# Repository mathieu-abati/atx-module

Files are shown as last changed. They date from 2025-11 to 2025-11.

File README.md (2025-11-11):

# RaspberryPi ATX PSU control module

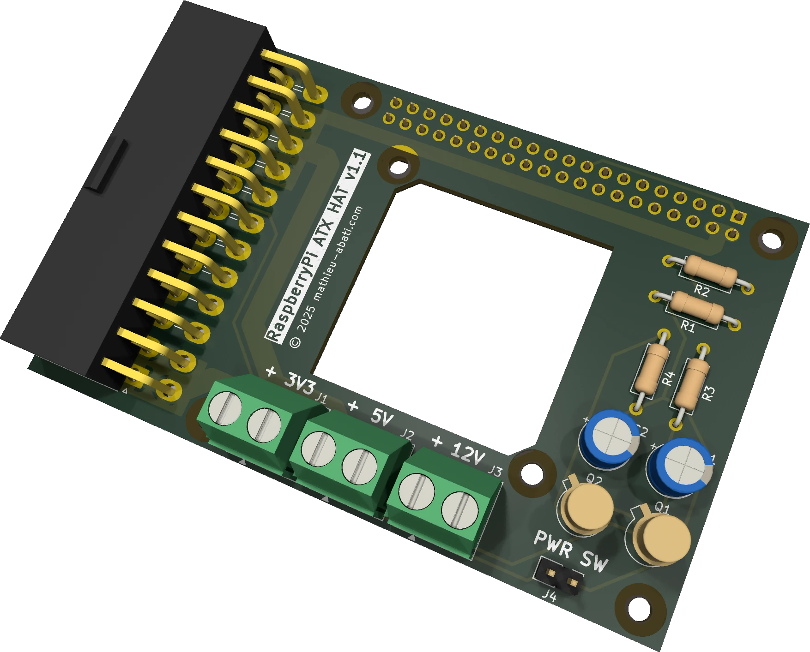
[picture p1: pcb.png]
PCB


With an ATX PSU powering a RaspberryPi, this circuit allows to control power ON / OFF from a single posh button.

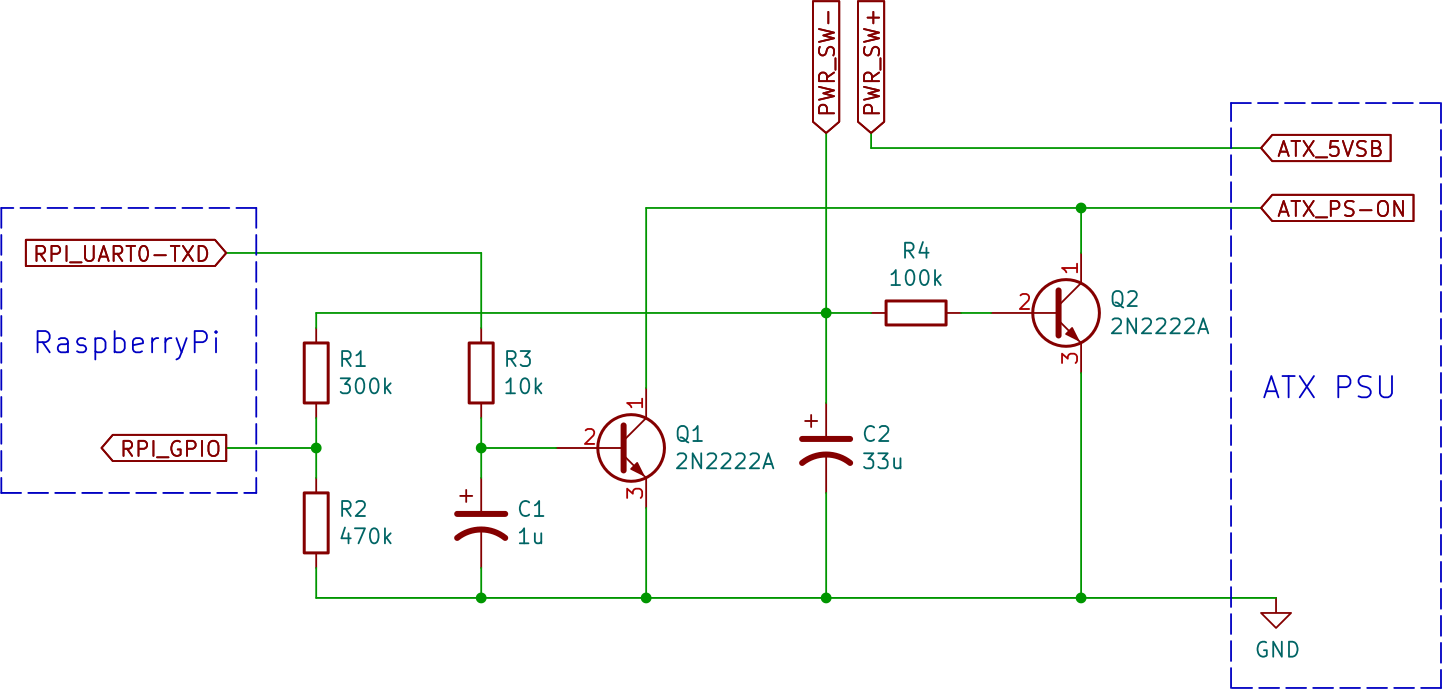
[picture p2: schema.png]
Schema


More details [on the project official page](https://mathieu-abati.com/en/projects/atx-module/).

## Compatibility

| Board | Tested | Working |
| --- | --- | --- |
| RaspberryPi 3 Model B  | ✅ | ✅ |
| RaspberryPi 3 Model B+ | ✅ | ✅ |
| RaspberryPi 4 2GB | ✅ | ✅ |
| RaspberryPi 5 2GB | ✅ | ❌ |

On RaspberryPi 5, power supply from extension connector is more complicated and is not working as-is with this module.

## Additional resources

For simulation, 2N2222A spice model file is not provided here du to license restrictions. You can download it
[from onSemi website](https://www.onsemi.com/download/models/txt/2n2222a.lib.txt),
and save it as `models/2N2222A.lib`.

For PCB 3D view, you may want the `ATX Connector 24pin 90deg.stp` file. You can
find it from [Grabcad](https://grabcad.com/library/90-atx-connector-24-pins-1).

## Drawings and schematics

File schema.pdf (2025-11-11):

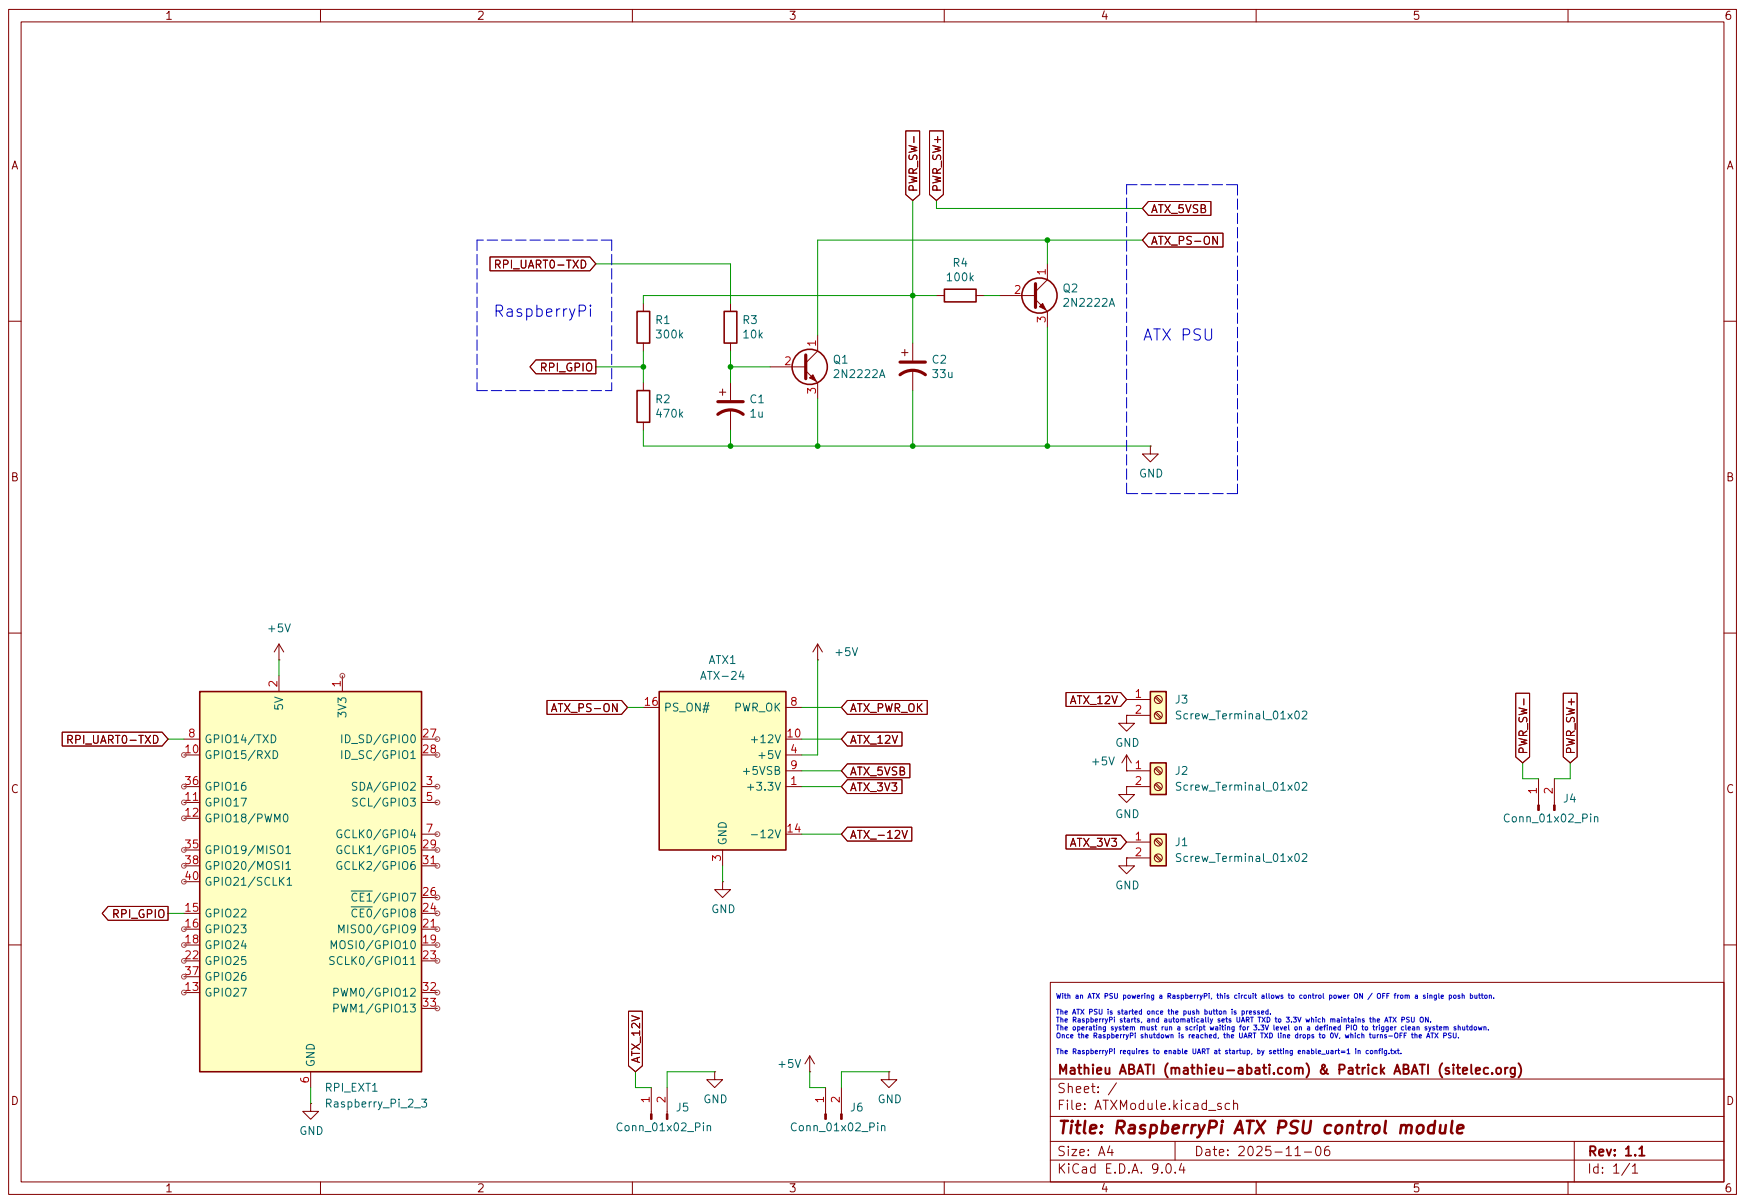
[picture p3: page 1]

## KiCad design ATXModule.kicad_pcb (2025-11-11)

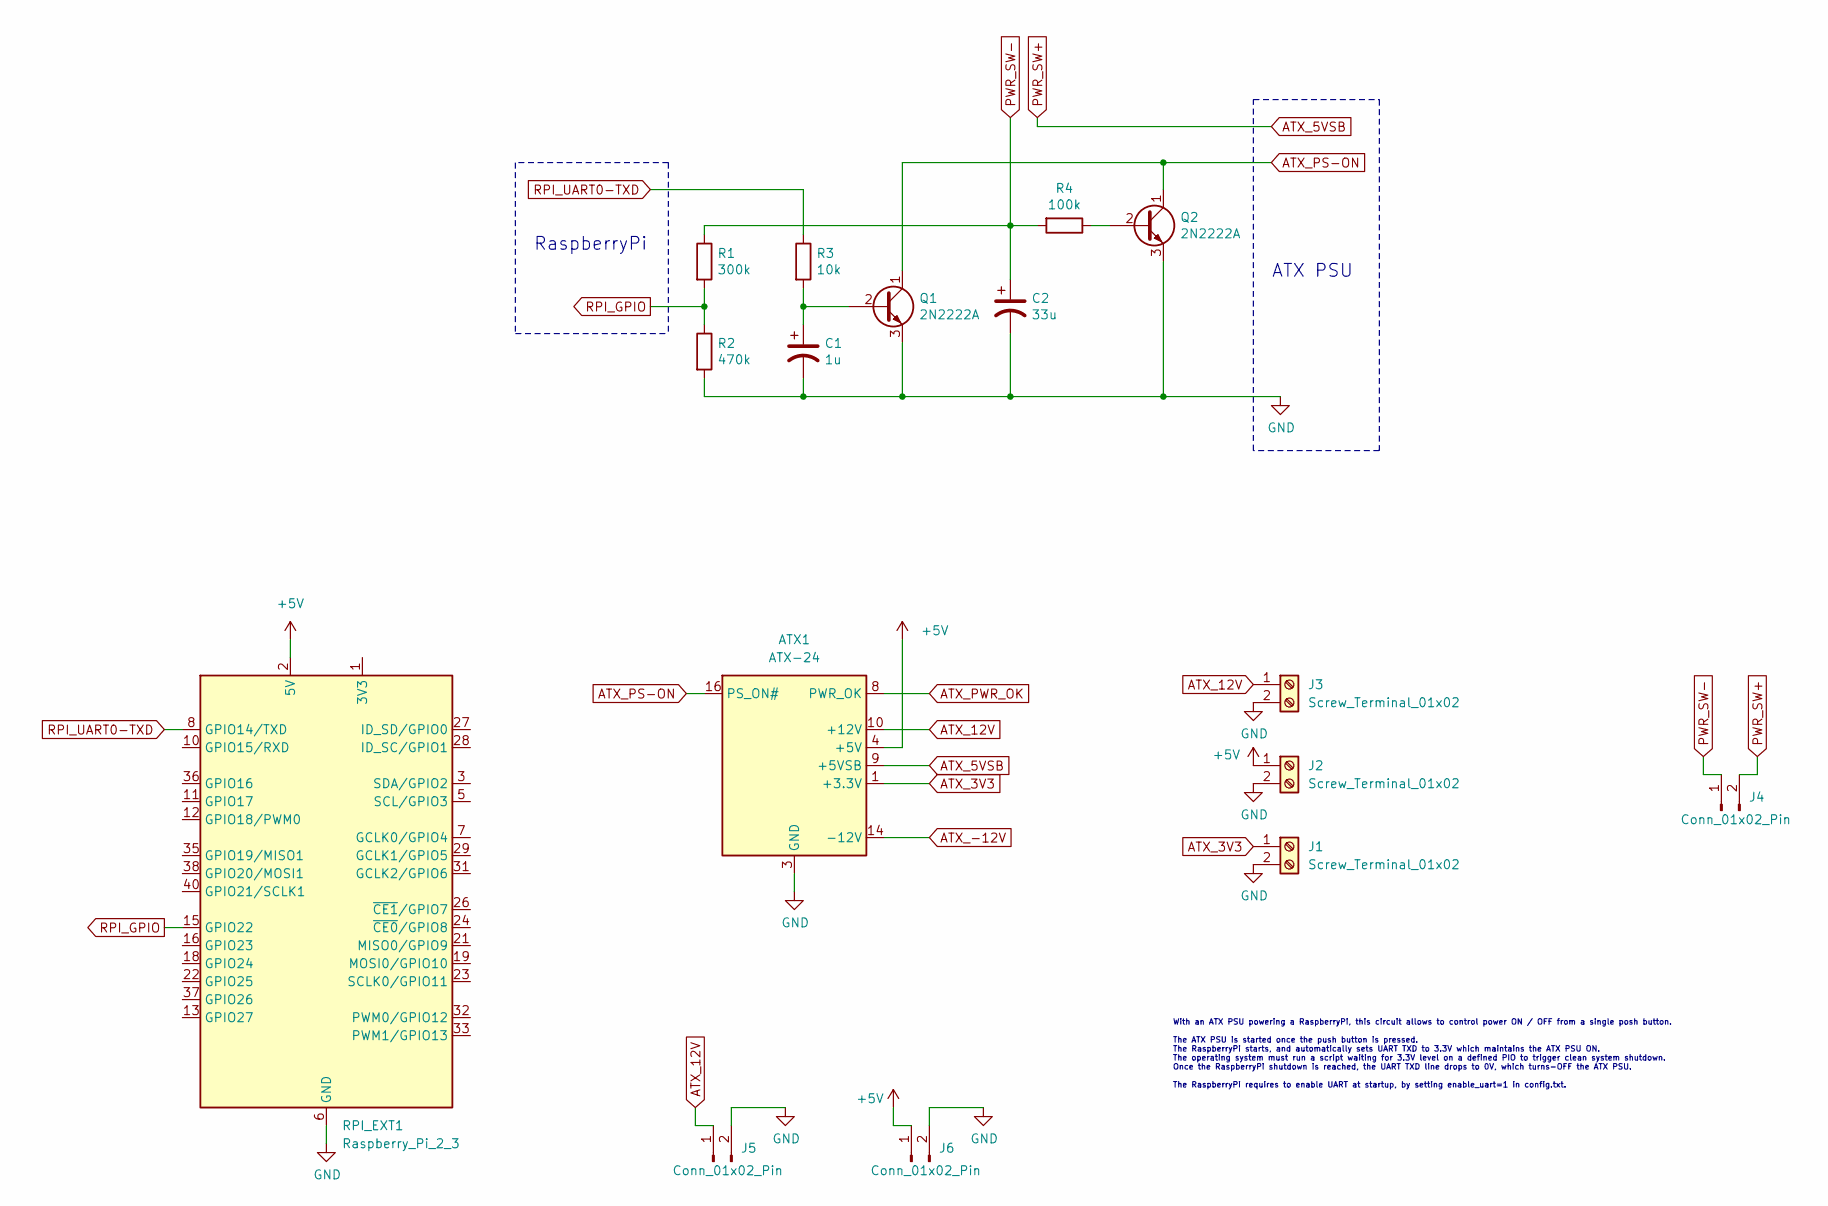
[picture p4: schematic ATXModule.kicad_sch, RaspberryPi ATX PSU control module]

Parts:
ATX1: ATX-24; Molex_Mini-Fit_Jr_5569-24A2_2x12_P4.20mm_Horizontal
C1: 1u; CP_Radial_D6.3mm_P2.50mm
C2: 33u; CP_Radial_D6.3mm_P2.50mm
J1, J2, J3: Screw_Terminal_01x02; TerminalBlock_Phoenix_MKDS-1,5-2_1x02_P5.00mm_Horizontal
J4: Conn_01x02_Pin; PinHeader_1x02_P2.54mm_Vertical
J5, J6: Conn_01x02_Pin; PinSocket_2x01_P2.54mm_Vertical_SMD
Q1, Q2: 2N2222A; TO-18-3
R1: 300k; R_Axial_DIN0207_L6.3mm_D2.5mm_P10.16mm_Horizontal
R2: 470k; R_Axial_DIN0207_L6.3mm_D2.5mm_P10.16mm_Horizontal
R3: 10k; R_Axial_DIN0207_L6.3mm_D2.5mm_P10.16mm_Horizontal
R4: 100k; R_Axial_DIN0207_L6.3mm_D2.5mm_P10.16mm_Horizontal
RPI_EXT1: Raspberry_Pi_2_3; PinSocket_2x20_P2.54mm_Vertical

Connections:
+5V: ATX1.4 (+5V), ATX1.6 (+5V), ATX1.21 (+5V), ATX1.22 (+5V), ATX1.23 (+5V), J2.1, J6.1, RPI_EXT1.2 (5V), RPI_EXT1.4 (5V)
ATX_3V3: ATX1.1 (+3.3V), ATX1.2 (+3.3V), ATX1.12 (+3.3V), ATX1.13 (+3.3V), J1.1
ATX_5VSB: ATX1.9 (+5VSB), J4.2
ATX_12V: ATX1.10 (+12V), ATX1.11 (+12V), J3.1, J5.1
ATX_-12V: ATX1.14 (-12V)
ATX_PS-ON: ATX1.16 (PS_ON#), Q1.1 (C), Q2.1 (C)
ATX_PWR_OK: ATX1.8 (PWR_OK)
GND: ATX1.3 (GND), ATX1.5 (GND), ATX1.7 (GND), ATX1.15 (GND), ATX1.17 (GND), ATX1.18 (GND), ATX1.19 (GND), ATX1.24 (GND), C1.2, C2.2, J1.2, J2.2, J3.2, J5.2, J6.2, Q1.3 (E), Q2.3 (E), R2.2, RPI_EXT1.6 (GND), RPI_EXT1.9 (GND), RPI_EXT1.14 (GND), RPI_EXT1.20 (GND), RPI_EXT1.25 (GND), RPI_EXT1.30 (GND), RPI_EXT1.34 (GND), RPI_EXT1.39 (GND)
unnamed: C1.1, Q1.2 (B), R3.2
unnamed: Q2.2 (B), R4.1
unnamed: RPI_EXT1.1 (3V3), RPI_EXT1.17 (3V3)
PWR_SW-: C2.1, J4.1, R1.1, R4.2
RPI_GPIO: R1.2, R2.1, RPI_EXT1.15 (GPIO22)
RPI_UART0-TXD: R3.1, RPI_EXT1.8 (GPIO14/TXD)

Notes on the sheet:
ATX PSU
With an ATX PSU powering a RaspberryPi, this circuit allows to control power ON / OFF from a single posh button. The ATX PSU is started once the push button is pressed. The RaspberryPi starts, and automatically sets UART TXD to 3.3V which maintains the ATX PSU ON. The operating system must run a sc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
RaspberryPi

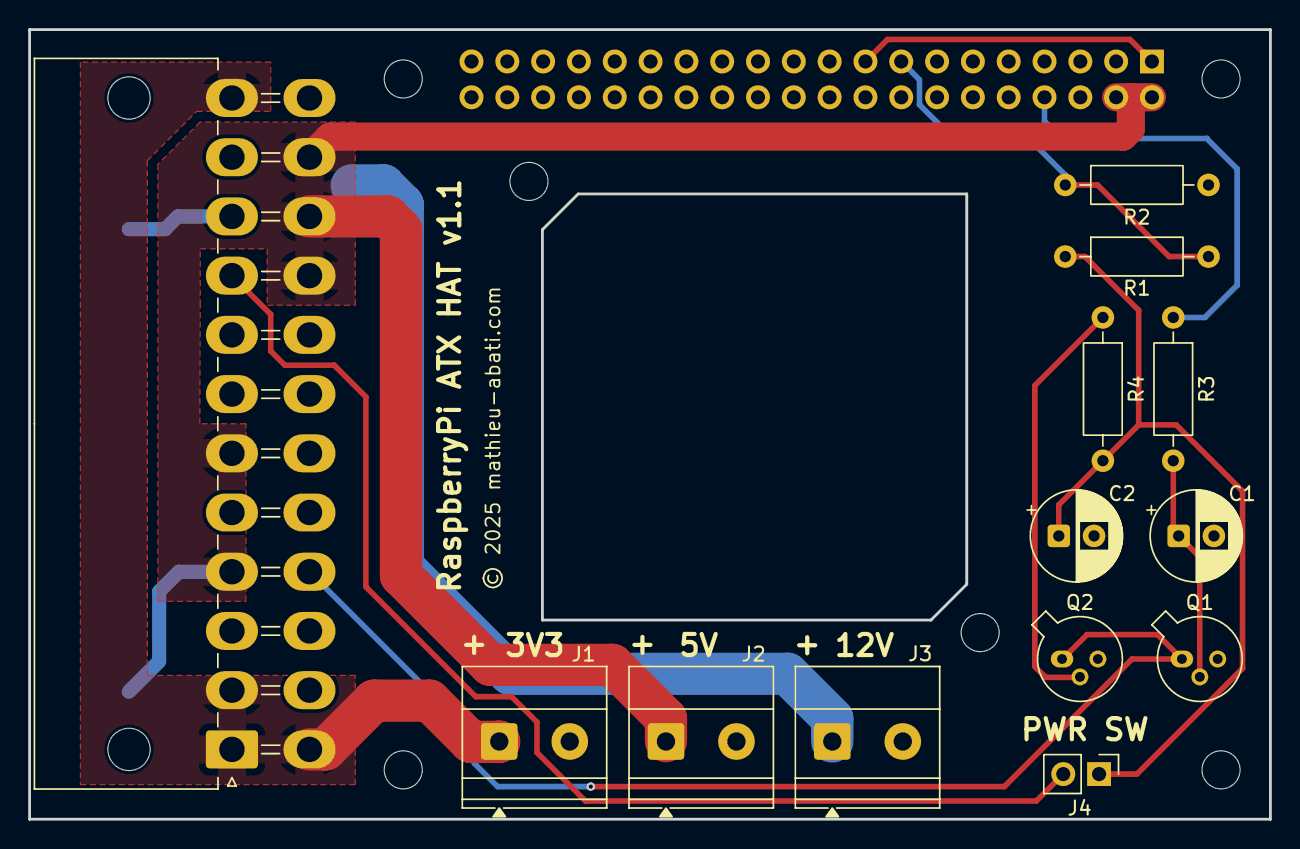
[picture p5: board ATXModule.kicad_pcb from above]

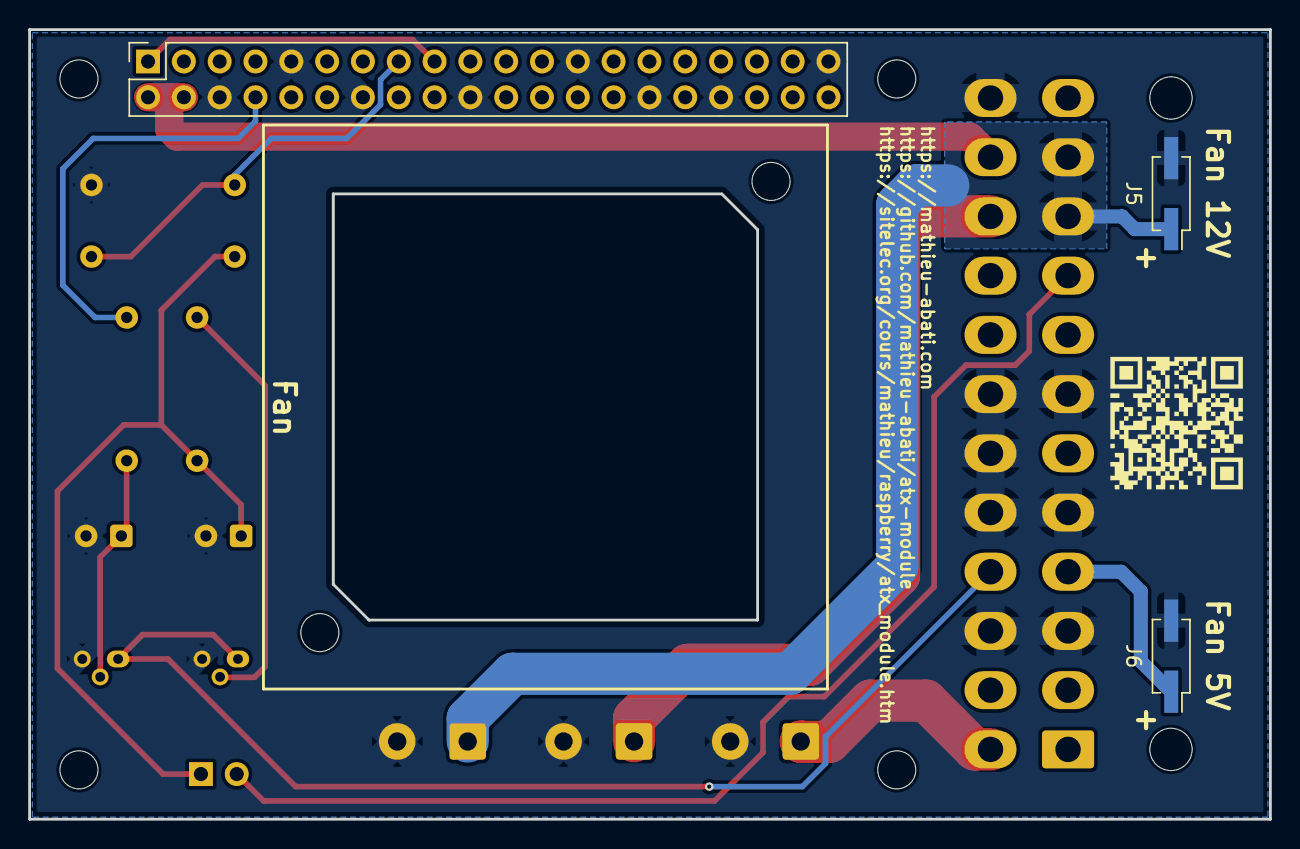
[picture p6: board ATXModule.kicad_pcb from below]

Board: 2 copper layers, 88.0 x 56.0 mm, 17 parts (4 on the bottom side), 12 nets.

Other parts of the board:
G1: LOGO; qr

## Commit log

2025-10-31 First release
    [ATXModule.sch, ATXModule_test.sch]
2025-11-09 Create PCB
    [ATXModule.kicad_pcb, ATXModule.kicad_sch, ATXModule.sch]
2025-11-10 PCB: improved some tracks placement
    [ATXModule.kicad_pcb]
2025-11-10 Add project page QR code silkscreen
    [ATXModule.kicad_pcb]
2025-11-10 Fix to support RaspberryPi 4
    [ATXModule.kicad_sch]
2025-11-10 33u capacitor is enough
    [ATXModule.kicad_sch]
2025-11-10 Update PCB
    [ATXModule.kicad_pcb]
2025-11-11 Add fan footprint, screw holes and connectors
    [ATXModule.kicad_pcb, ATXModule.kicad_sch]
2025-11-11 Add PCB 3D rendered picture
2025-11-11 Update schema with fan connectors

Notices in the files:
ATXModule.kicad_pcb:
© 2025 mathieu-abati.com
